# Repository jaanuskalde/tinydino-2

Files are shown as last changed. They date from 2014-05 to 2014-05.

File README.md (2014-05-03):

tinydino-2
==========

Smallest Arduino clone possible to make!

2014 Jaanus Kalde
jaanus.tech-thing.org

FEATURES
--------

   * Arduino compatible
   * Smallest size possible (7.4mm x 7.4mm)
   * Auto reset
   * UART
   * SPI
   * 4 analog inputs
   * 1 digital i/o
   * Now with wings! To ease with programming.

BOM (with farnell codes)
------------------------

    QFN28 atmega88 - 1748530
    8MHz resonator - 1615352
    10k 0603 resistor
    1k 0603 resistor
    0603 red led
    100nF 0603 capacitor

Its free - share!

http://creativecommons.org/licenses/by-nc-sa/3.0/

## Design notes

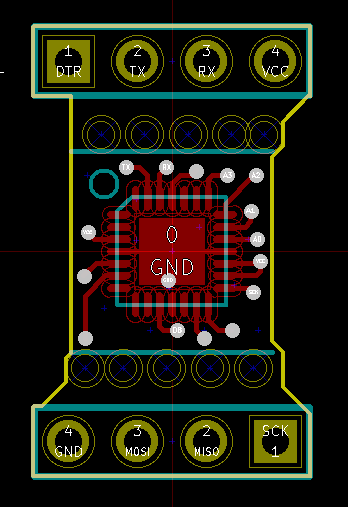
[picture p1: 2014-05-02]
Top_side.png

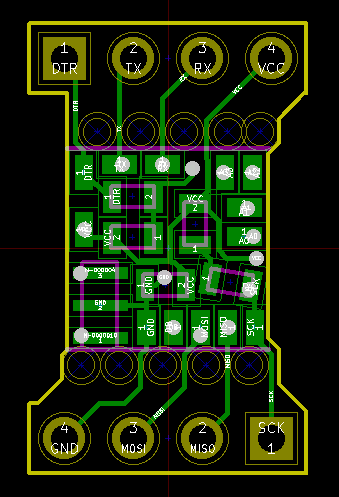
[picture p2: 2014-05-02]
Bottom_side.png

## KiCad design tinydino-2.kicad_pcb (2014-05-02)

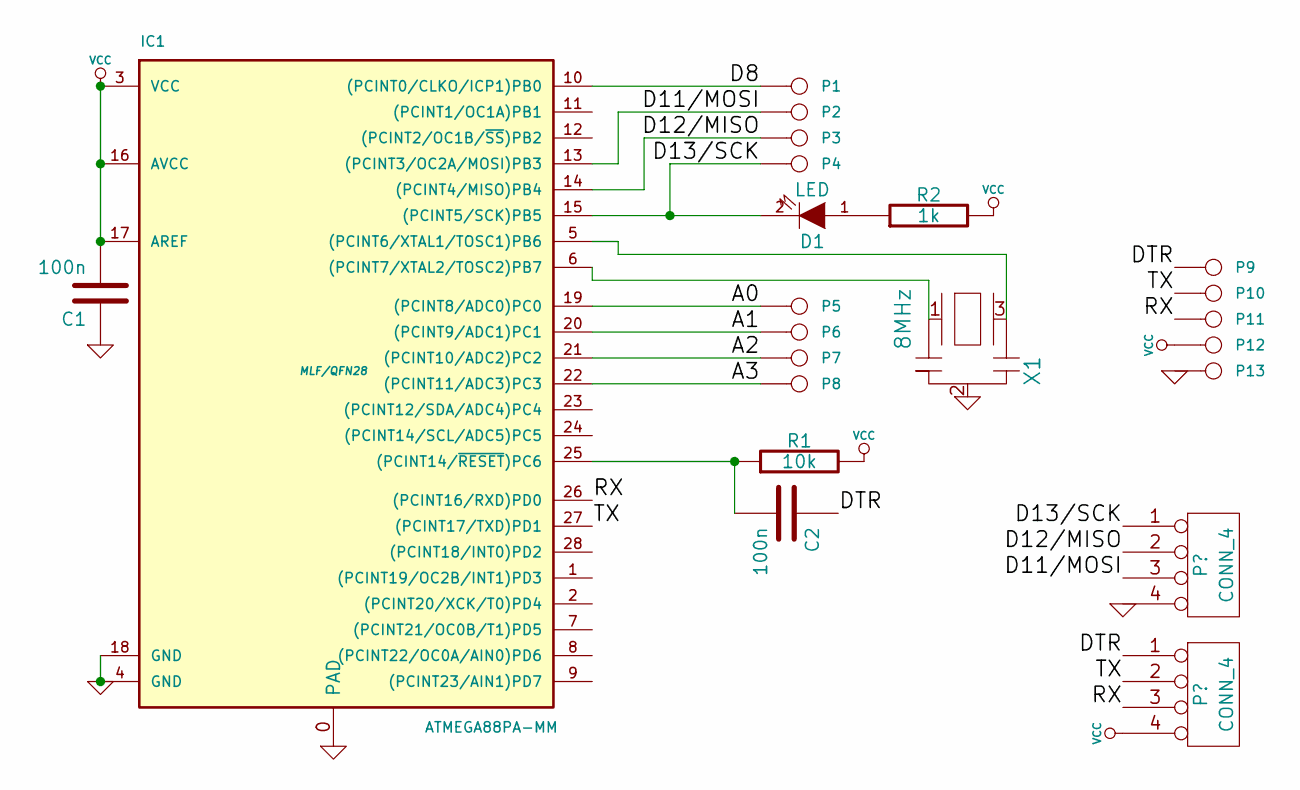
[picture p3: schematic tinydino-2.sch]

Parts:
C1, C2: 100n
D1: LED
IC1: ATMEGA88PA-MM; MLF/QFN28
P1, P2, P3, P4, P5, P6, P7, P8, P9, P10, P11, P12, P13: CONN_1
R1: 10k
R2: 1k
X1: 8MHz

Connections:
/A0: IC1.19 ((PCINT8/ADC0)PC0), P5.1
/A1: IC1.20 ((PCINT9/ADC1)PC1), P6.1
/A2: IC1.21 ((PCINT10/ADC2)PC2), P7.1
/A3: IC1.22 ((PCINT11/ADC3)PC3), P8.1
/D8: IC1.10 ((PCINT0/CLKO/ICP1)PB0), P1.1
/D11/MOSI: IC1.13 ((PCINT3/OC2A/MOSI)PB3), P2.1; also elsewhere on the board
/D12/MISO: IC1.14 ((PCINT4/MISO)PB4), P3.1; also elsewhere on the board
/D13/SCK: D1.2 (K), IC1.15 ((PCINT5/SCK)PB5), P4.1; also elsewhere on the board
/DTR: C2.1, P9.1; also elsewhere on the board
/RX: IC1.26 ((PCINT16/RXD)PD0), P11.1; also elsewhere on the board
/TX: IC1.27 ((PCINT17/TXD)PD1), P10.1; also elsewhere on the board
GND: C1.1, IC1.0 (PAD), IC1.4 (GND), IC1.18 (GND), P13.1, X1.2; also elsewhere on the board
unnamed: IC1.5 ((PCINT6/XTAL1/TOSC1)PB6), X1.3
unnamed: IC1.6 ((PCINT7/XTAL2/TOSC2)PB7), X1.1
unnamed: C2.2, IC1.25 ((PCINT14/~RESET~)PC6), R1.1
unnamed: D1.1 (A), R2.1
VCC: C1.2, IC1.3 (VCC), IC1.16 (AVCC), IC1.17 (AREF), P12.1, R1.2, R2.2; also elsewhere on the board

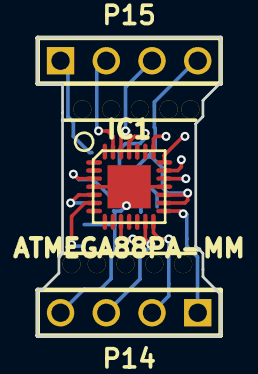
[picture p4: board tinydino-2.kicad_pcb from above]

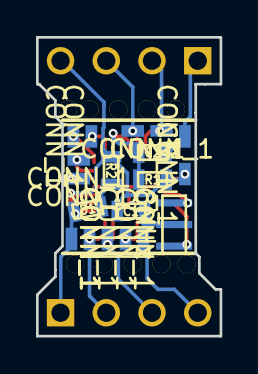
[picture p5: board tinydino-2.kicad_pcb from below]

Board: 2 copper layers, 10.2 x 16.6 mm, 32 parts (19 on the bottom side), 17 nets.

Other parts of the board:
P14, P15: CONN_4; conn_4
drill_1mm, drill_1mm#2, drill_1mm#3, drill_1mm#4, drill_1mm#5, drill_1mm#6, drill_1mm#7, drill_1mm#8, drill_1mm#9, drill_1mm#10: VAL**; drill_1mm

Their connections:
/D11/MOSI: P14.3; also elsewhere on the board
/D12/MISO: P14.2; also elsewhere on the board
/D13/SCK: P14.1; also elsewhere on the board
/DTR: P15.1; also elsewhere on the board
/RX: P15.3; also elsewhere on the board
/TX: P15.2; also elsewhere on the board
GND: P14.4; also elsewhere on the board
VCC: P15.4; also elsewhere on the board
